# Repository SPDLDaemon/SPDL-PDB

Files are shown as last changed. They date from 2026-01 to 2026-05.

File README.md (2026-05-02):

# Smart Product Design Lab - Power Distribution Board v2.1
## features
* 16 JST XH plugs with 3.3v ground and 5 volts
* 8 molex 254 plugs for servos

## user guide image
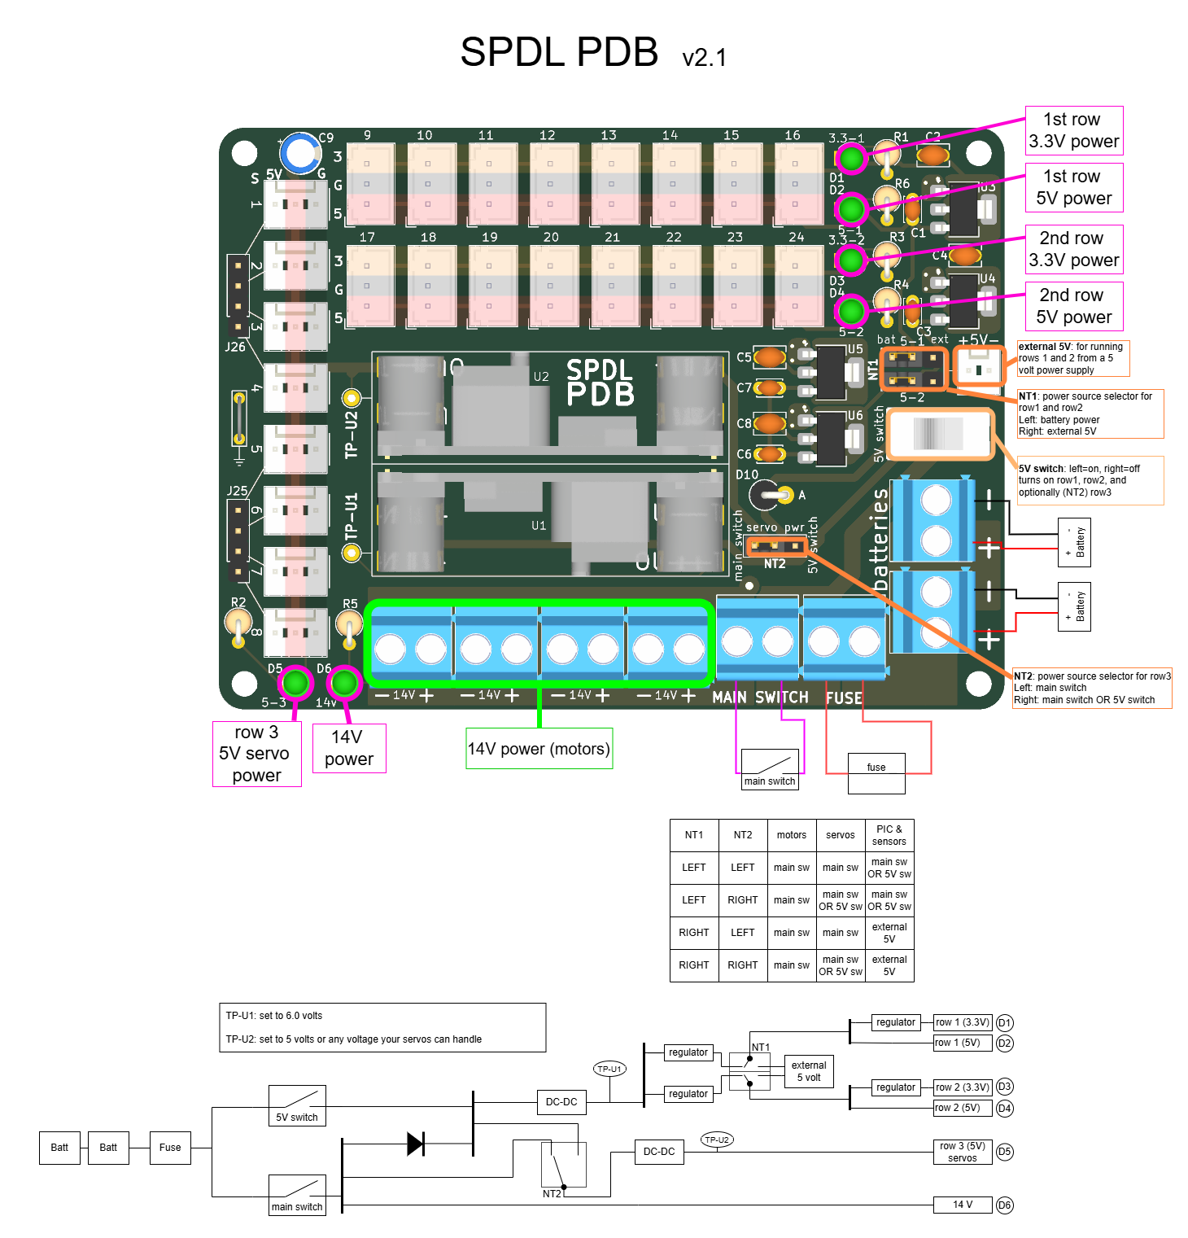
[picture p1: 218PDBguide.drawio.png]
218PDBguide

#### [link to user guide image](/218PDBguide.drawio.png)

### [link to schematic](/schematic.pdf)
#### [link to image of PCB traces](/pcb.pdf)
<!-- ### board explanation video coming soon -->

## assembly
### [assembly instructions](/assembly_instructions.md)

[Interactive BOM](/ibom.html) (download file and open in a browser)

<!-- ### assembly video coming soon -->

## current limits:
* board total: 16 amps (theoretical) ??? amps (tested), limited by the traces and main battery screw terminals
* 5-3: 2 amps (theoretical) ??? amps (tested), limited by the HW-411 buck voltage regulator
* 3.3-1 + 5-1: 1 amp (theoretical) ??? amps (tested), limited by the TLV761 linear voltage regulator
* 3.3-2 + 5-2: 1 amp (theoretical) ??? amps (tested), limited by the TLV761 linear voltage regulator

## images
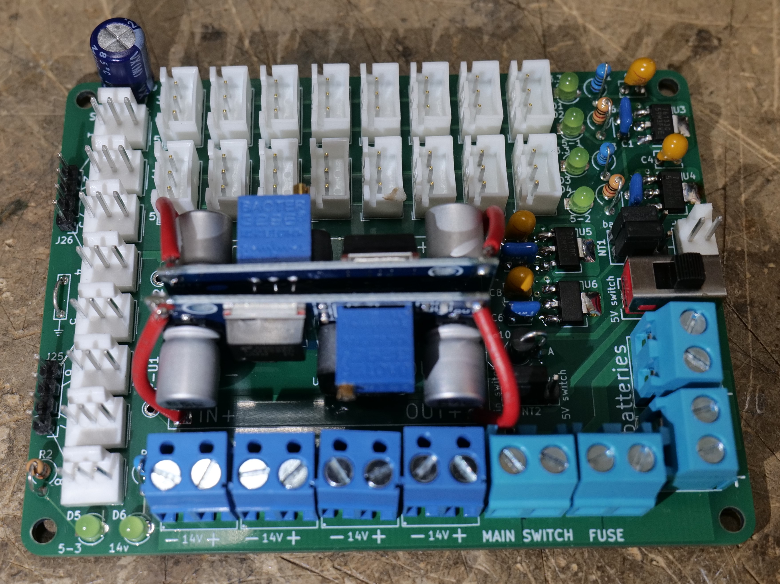
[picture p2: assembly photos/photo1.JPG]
assembled board

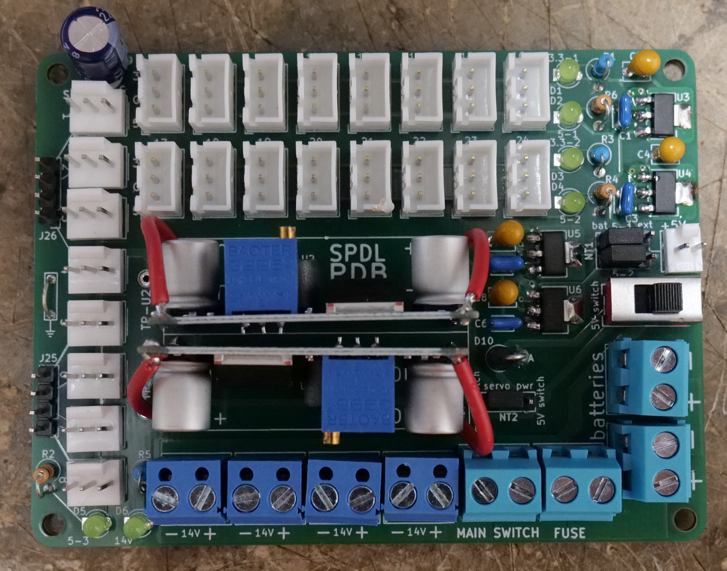
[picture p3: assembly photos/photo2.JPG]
top view


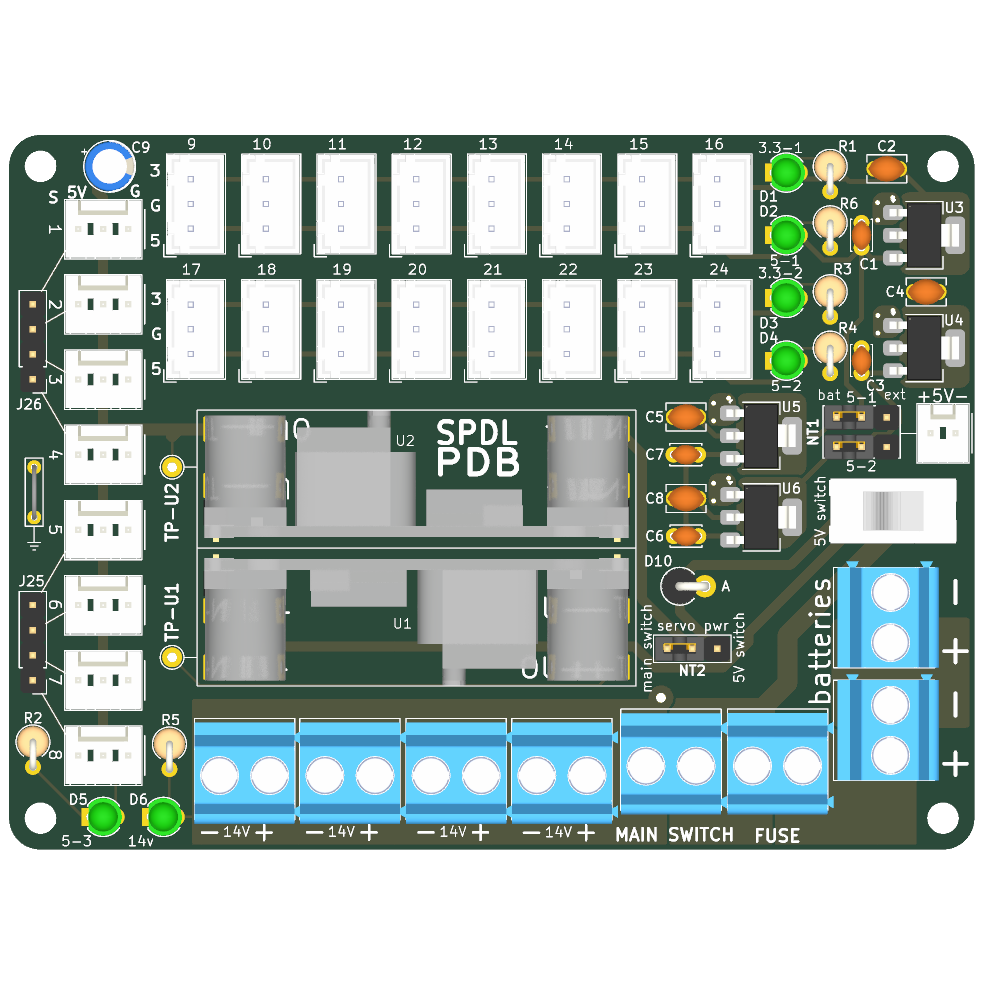
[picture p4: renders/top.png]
render of board

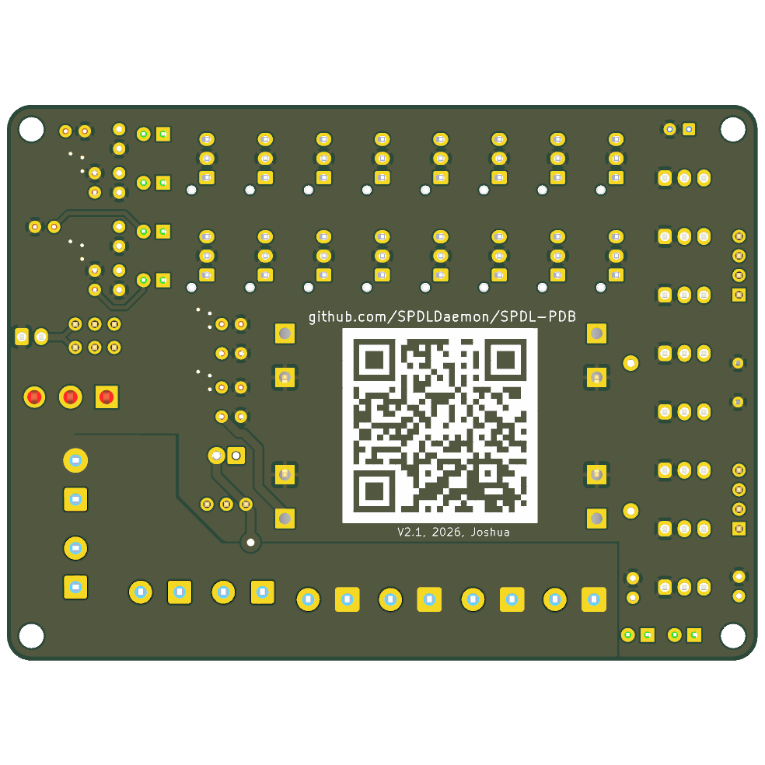
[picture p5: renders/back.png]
render of board back

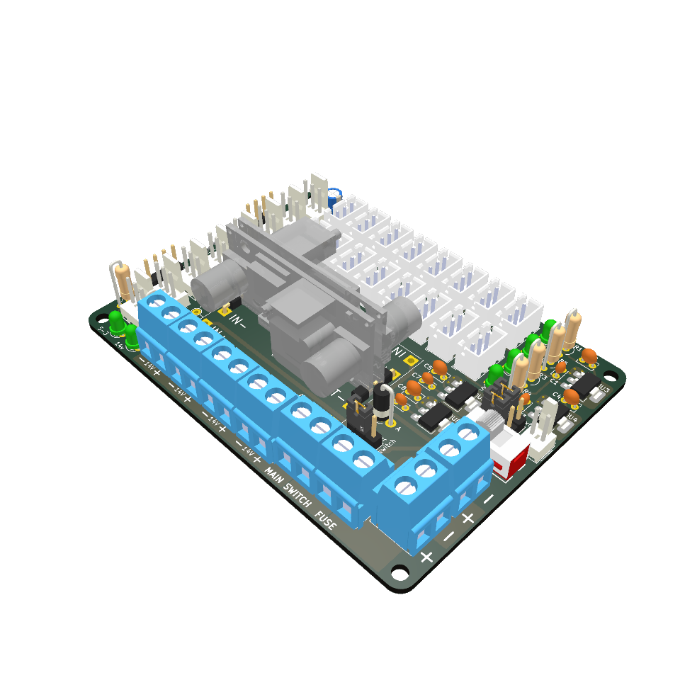
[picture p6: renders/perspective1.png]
render of board perspective1

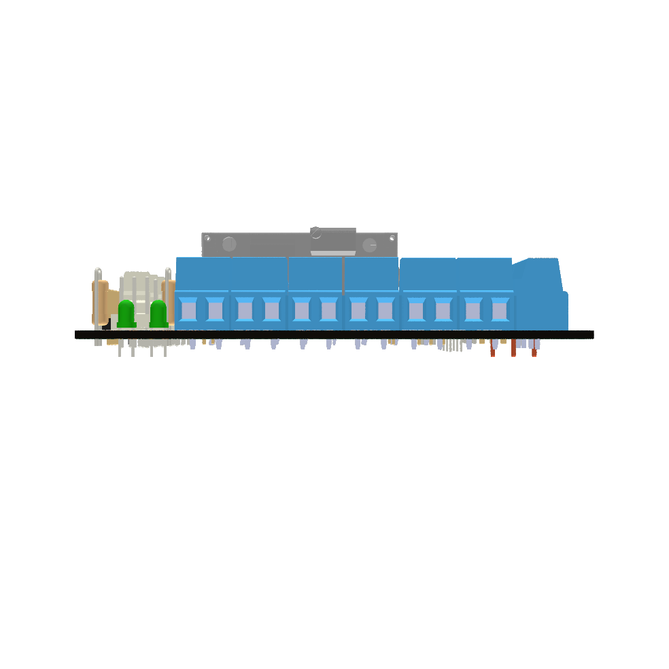
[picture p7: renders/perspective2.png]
render of board perspective2


## KiCAD Symbols
### [simple symbol](https://github.com/SPDLDaemon/SPDL-PDB/blob/main/pdb.kicad_sym)
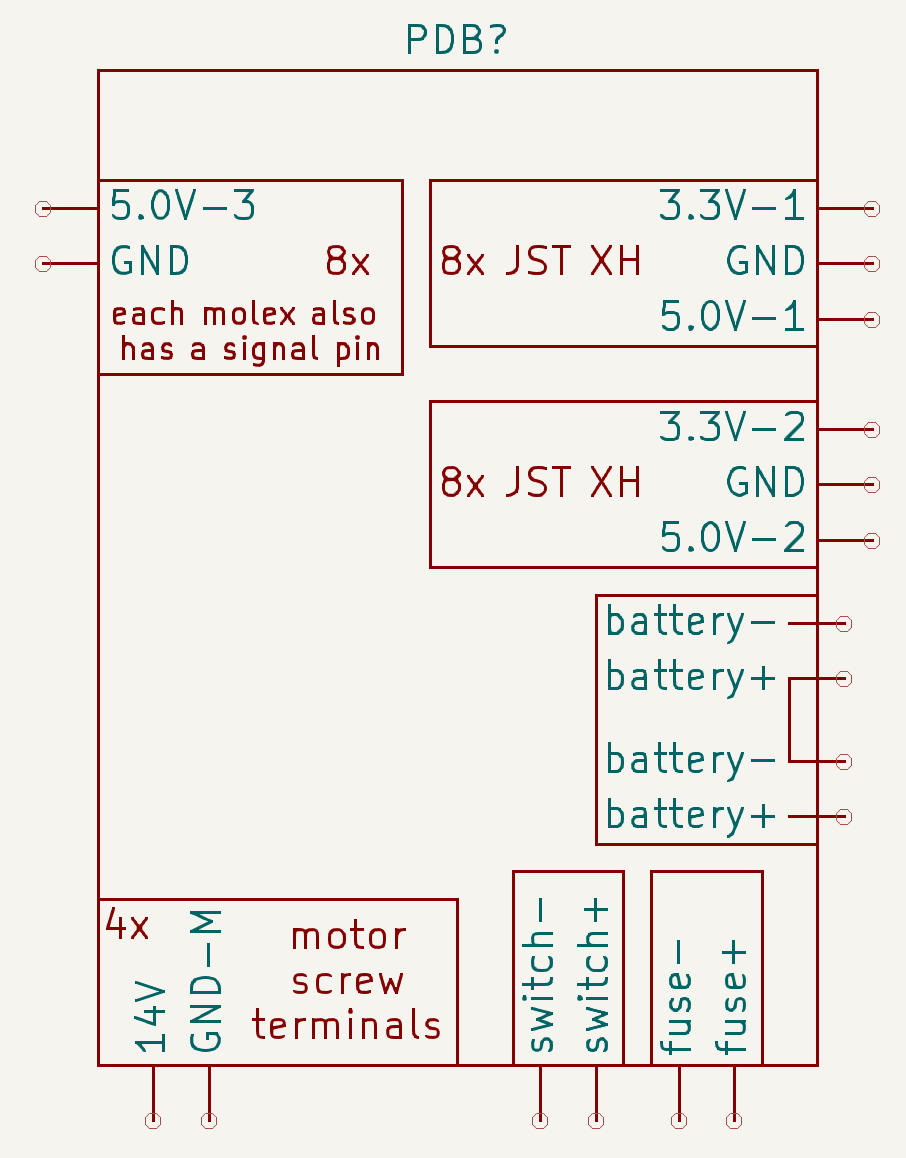
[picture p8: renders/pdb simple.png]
simple

### [detailed symbol](https://github.com/SPDLDaemon/SPDL-PDB/blob/main/pdb-detailed.kicad_sym)
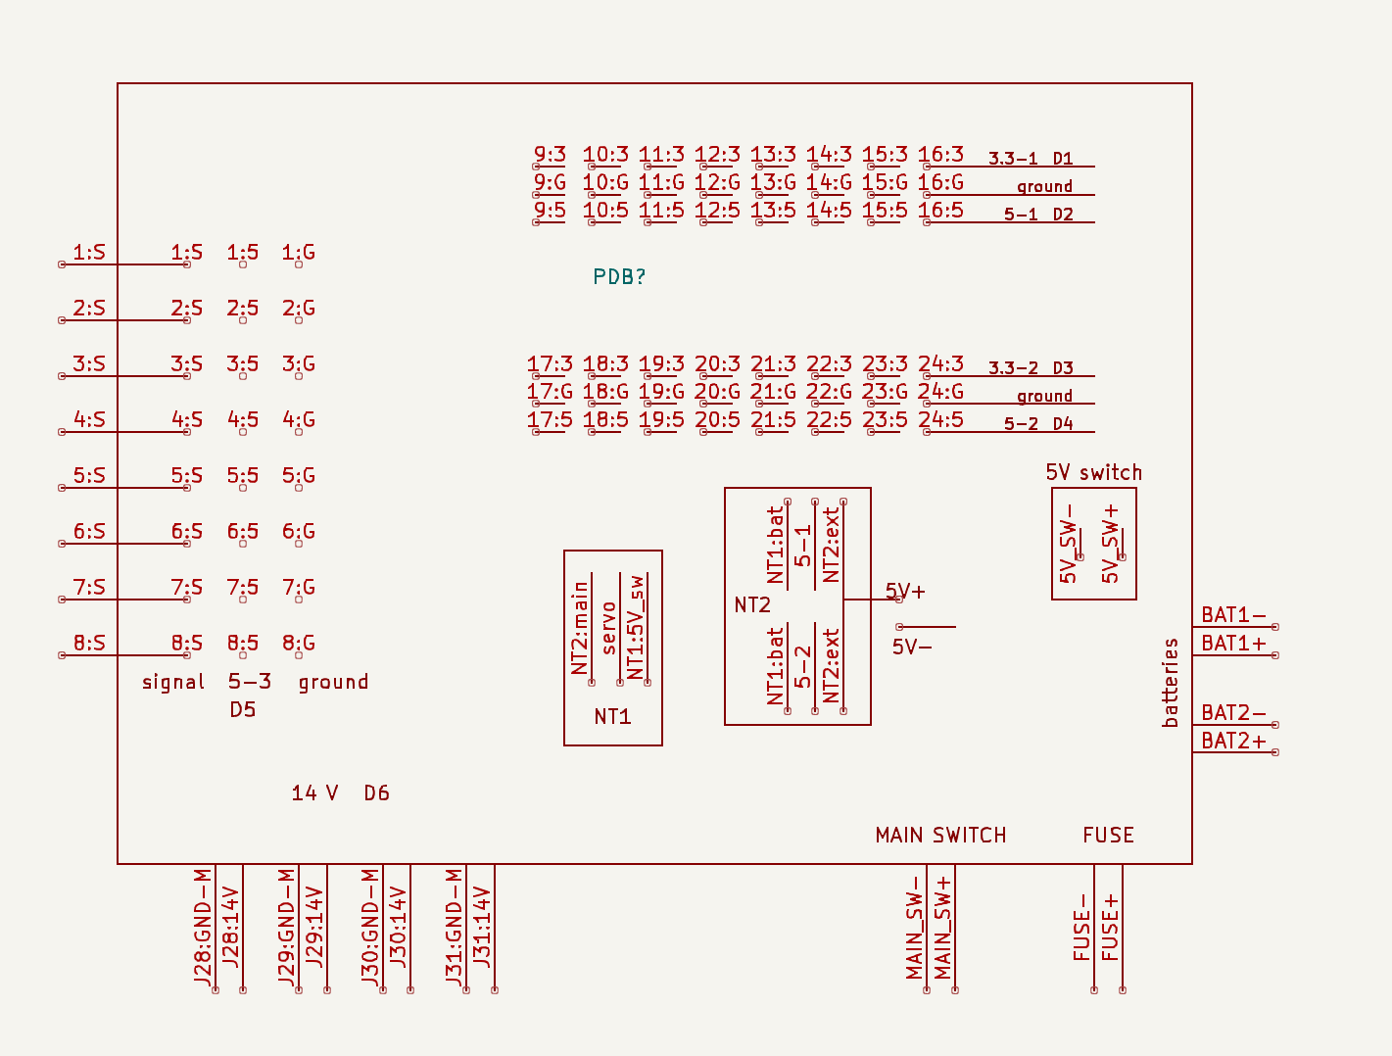
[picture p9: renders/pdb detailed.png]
detailed


## buying PCBs and components 
1x set of components from [bill of materials](/BOM.csv)

2x tamiya connectors for batteries (with wires)

1x main power switch (for example 141-RCA1913F1ABLKBLKWHT3-ND)

1x fuse holder (with wires) and fuse

1x PCB from ([gerber files](/gerbers.zip))

JST XH socket housings (16) 455-2219-ND

JST XH socket crimps (48) 455-1135-1000-ND

4 inches of 18 AWG wire

small flathead screwdriver

JST XH crimper

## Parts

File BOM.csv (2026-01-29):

Reference | Value | Footprint | Part_Number | QUANTITY
C1,C3,C6,C7 | 0.1 uF | Capacitor_THT:C_Disc_D3.0mm_W2.0mm_P2.50mm | 0.1 uF ceramic capacitor | 4
C2,C4,C5,C8 | 10 uF | Capacitor_THT:C_Disc_D3.8mm_W2.6mm_P2.50mm | 10uF tantalum (polarized) capacitor | 4
C9 | 220 uF | Capacitor_THT:CP_Radial_D5.0mm_P2.50mm | 220uf electrolytic | 1
D1-D6 | LED | 218-pdb:LED_D3.0mm | 3 mm diameter LED | 6
D10 | diode, >=2 Amp | Diode_THT:D_DO-15_P2.54mm_Vertical_AnodeUp | >=2 Amp diode, e.g. Diotec 1N5060 | 1
FID1-FID4 | 90 degree header pin | 218-pdb:PinHeader_1x01_P2.54mm_H | 90 degree header pin | 4
FID5,FID6,FID10 | jumper | 218-pdb:jumper | pin jumper 0.1" pitch Sullins QPC02SXGN-RC | 3
Fuse1 | fuse | 218-pdb:CUI_TB007-508-02BE | screw terminal, 5.08" pitch, TB007-508-02BE | 1
J1-J16 | Conn_01x03 | 218-pdb:JST_XH_B3B-XH-AM_1x03_P2.50mm_Vertical | 3 pin JST XH | 16
J17-J24 | Conn_01x03 | 218-pdb:Molex_KK-254_AE-6410-03A_1x03_P2.54mm_Vertical | 3 pin KK254 molex 0022232031 | 8
J25,J26 | Conn_01x04_Pin | Connector_PinHeader_2.54mm:PinHeader_1x04_P2.54mm_Vertical | 4 header pins 0.1" pitch | 2
J27 | external 5V | 218-pdb:Molex_KK-254_AE-6410-02A_1x02_P2.54mm_Vertical | 2 pin KK 254 molex 0022232021 | 1
J28-J31 | 14v | 218-pdb:CUI_TB007-508-02BE | screw terminal, 5.08" pitch, TB007-508-02BE | 4
J32,J33 | battery | 218-pdb:CUI_TB007-508-02BE | screw terminal, 5.08" pitch, TB007-508-02BE | 2
main1 | MainSW | 218-pdb:CUI_TB007-508-02BE | screw terminal, 5.08" pitch, TB007-508-02BE | 1
NT1 | SW_Slide_DPDT | 218-pdb:PinHeader_2x03_P2.54mm_Vertical | 2x3 header pins | 1
NT2 | ~ | 218-pdb:PinHeader_1x03_P2.54mm_Vertical | 3 header pins 0.1" pitch | 1
R1,R3 | 680 | Resistor_THT:R_Axial_DIN0309_L9.0mm_D3.2mm_P2.54mm_Vertical | spdl | 2
R2,R4,R6 | 1k | Resistor_THT:R_Axial_DIN0309_L9.0mm_D3.2mm_P2.54mm_Vertical | spdl | 3
R5 | 3.3k | Resistor_THT:R_Axial_DIN0309_L9.0mm_D3.2mm_P2.54mm_Vertical | spdl | 1
SW1 | 5V switch | 218-pdb:1101A4CQEA | 1101A4CQEA | 1
TP1 | ground | TestPoint:TestPoint_Bridge_Pitch5.08mm_Drill0.7mm | piece of wire | 1
U1,U2 | DC-DC buck | 218-pdb:HW-411 | HW-411 lm2596 buck converter module | 2
U3,U4 | TLV76133DCY | Package_TO_SOT_SMD:SOT-223-3_TabPin2 | TLV76133DCY | 2
U5,U6 | TLV76150DCY | Package_TO_SOT_SMD:SOT-223-3_TabPin2 | TLV76150DCY | 2

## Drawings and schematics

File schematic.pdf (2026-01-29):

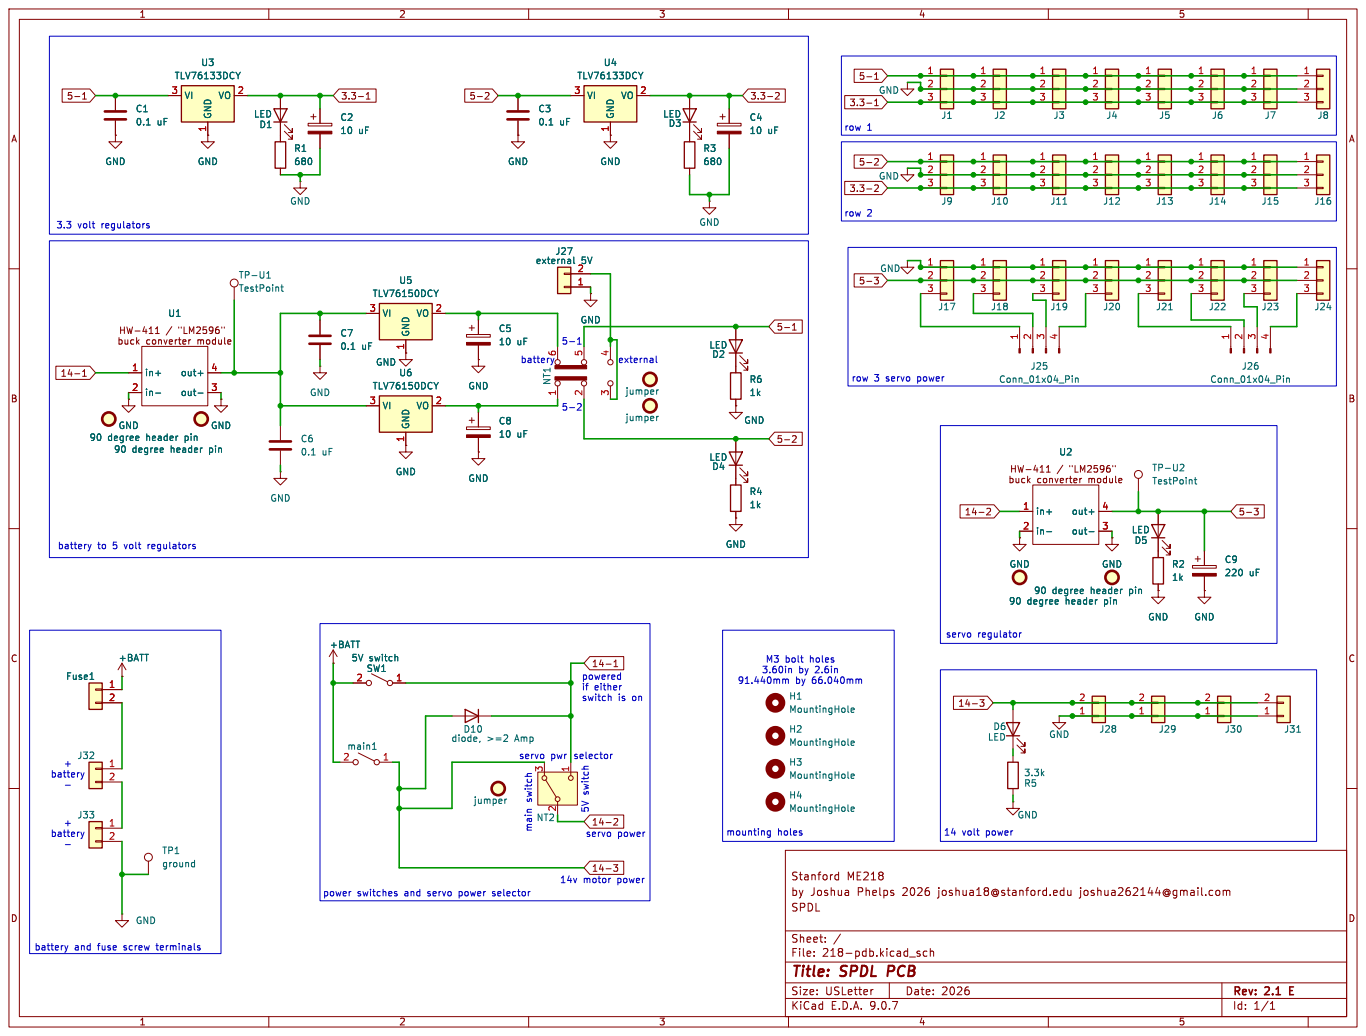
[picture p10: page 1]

J26 Conn_01x04_Pin C6
row 3 servo power power switches and servo power selector
10 uF GND

90 degree header pin GND

battery to 5 volt regulators

powered
if either switch is on

File: 218-pdb.kicad_sch Sheet: / SPDL

battery and fuse screw terminals

Id: 1/1 Title: SPDL PCB

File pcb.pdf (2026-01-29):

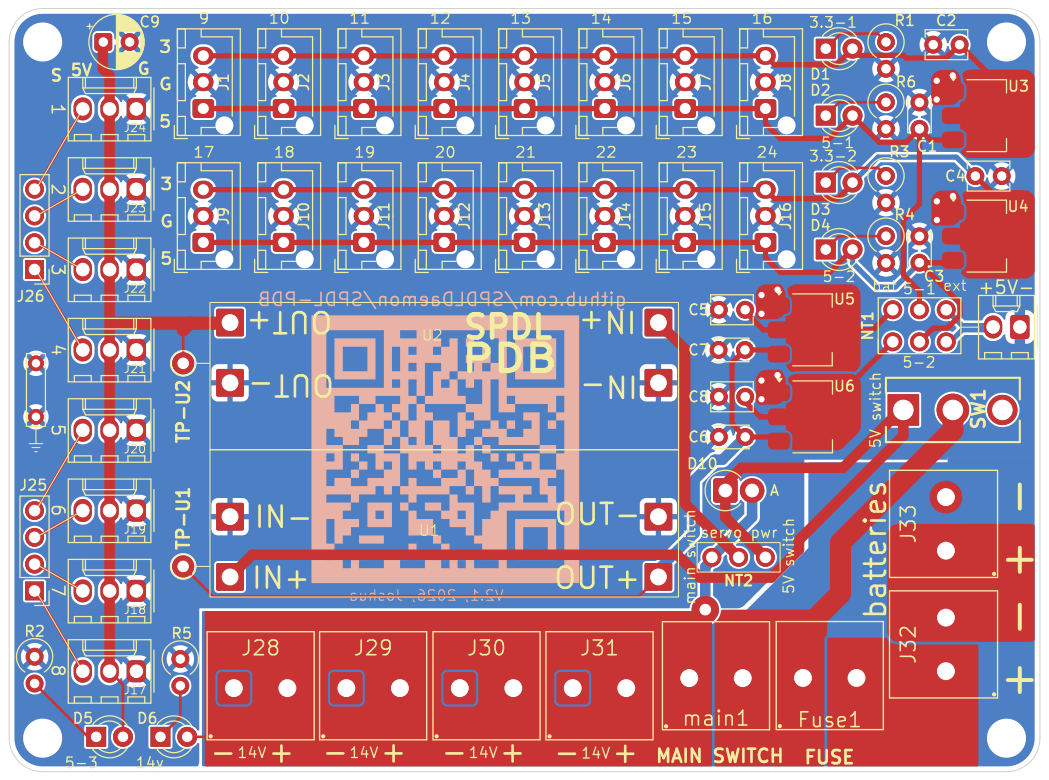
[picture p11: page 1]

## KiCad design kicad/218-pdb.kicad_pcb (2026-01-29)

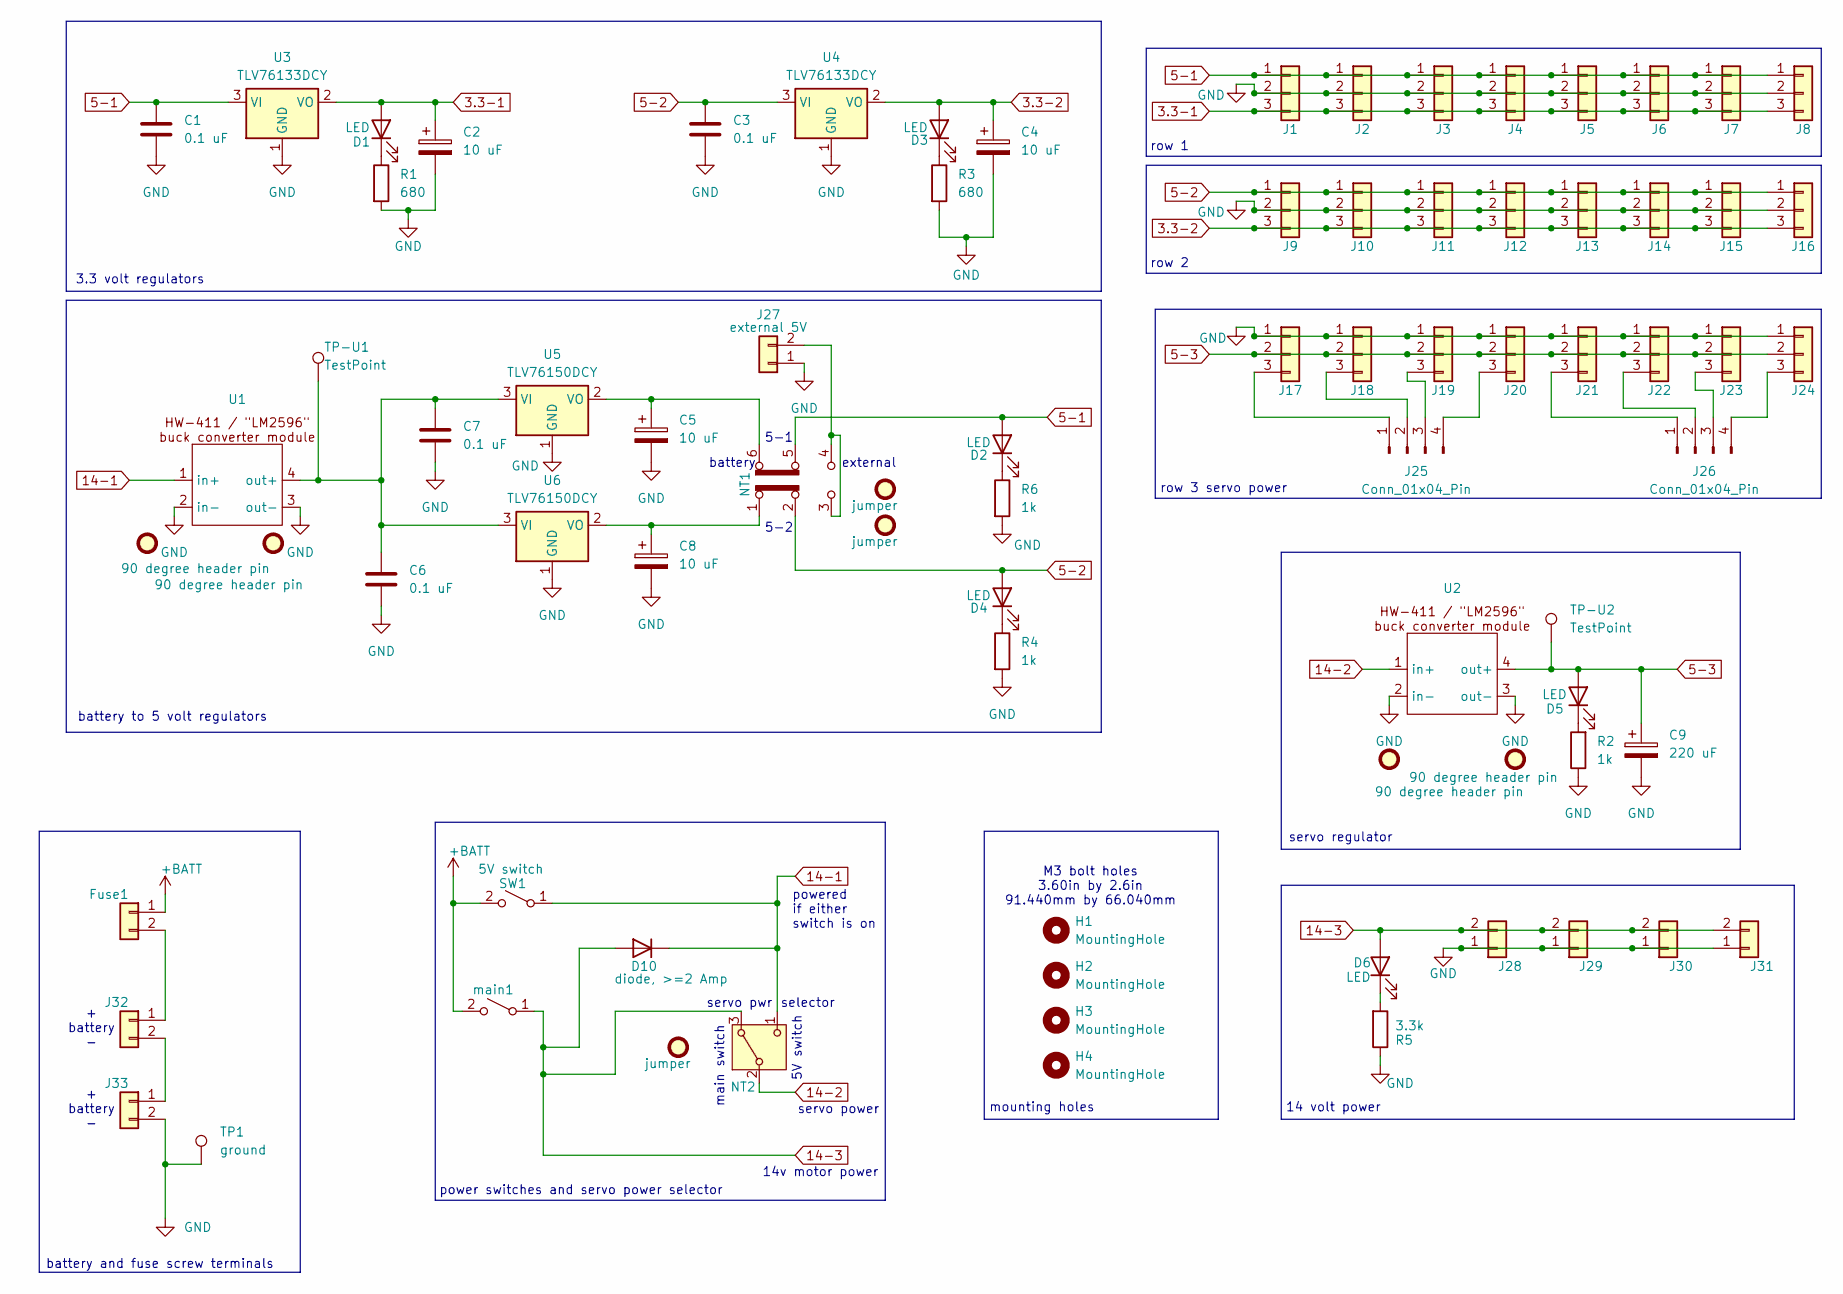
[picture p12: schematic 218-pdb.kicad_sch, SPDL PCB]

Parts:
C1, C3, C6, C7: 0.1 uF; C_Disc_D3.0mm_W2.0mm_P2.50mm; Part_Number 0.1 uF ceramic capacitor
C2, C4, C5, C8: 10 uF; C_Disc_D3.8mm_W2.6mm_P2.50mm; Part_Number 10uF tantalum (polarized) capacitor
C9: 220 uF; CP_Radial_D5.0mm_P2.50mm; Part_Number 220uf electrolytic
D1, D2, D3, D4, D5, D6: LED; LED_D3.0mm; Part_Number 3 mm diameter LED
D10: diode, >=2 Amp; D_DO-15_P2.54mm_Vertical_AnodeUp; Part_Number >=2 Amp diode, e.g. Diotec 1N5060
FID1, FID2, FID3, FID4: 90 degree header pin; PinHeader_1x01_P2.54mm_H; Part_Number 90 degree header pin
FID5, FID6, FID10: jumper; Part_Number pin jumper 0.1" pitch Sullins QPC02SXGN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
Fuse1: fuse; CUI_TB007-508-02BE; Part_Number screw terminal, 5.08" pitch, TB007-508-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
H1, H2, H3, H4: MountingHole; MountingHole_3.2mm_M3_ISO7380
J1, J2, J3, J4, J5, J6, J7, J8, J9, J10, J11, J12, J13, J14, J15, J16: Conn_01x03; JST_XH_B3B-XH-AM_1x03_P2.50mm_Vertical; Part_Number 3 pin JST XH
J17, J18, J19, J20, J21, J22, J23, J24: Conn_01x03; Molex_KK-254_AE-6410-03A_1x03_P2.54mm_Vertical; Part_Number 3 pin KK254 molex 0022232031
J25, J26: Conn_01x04_Pin; PinHeader_1x04_P2.54mm_Vertical; Part_Number 4 header pins 0.1" pitch
J27: external 5V; Molex_KK-254_AE-6410-02A_1x02_P2.54mm_Vertical; Part_Number 2 pin KK 254 molex 0022232021
J28, J29, J30, J31: 14v; CUI_TB007-508-02BE; Part_Number screw terminal, 5.08" pitch, TB007-508-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
J32, J33: battery; CUI_TB007-508-02BE; Part_Number screw terminal, 5.08" pitch, TB007-508-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
NT1: SW_Slide_DPDT; PinHeader_2x03_P2.54mm_Vertical; Part_Number 2x3 header pins
NT2: PinHeader_1x03_P2.54mm_Vertical; Part_Number 3 header pins 0.1" pitch
R1, R3: 680; R_Axial_DIN0309_L9.0mm_D3.2mm_P2.54mm_Vertical; Part_Number spdl; digikey_part_number n/a
R2, R4, R6: 1k; R_Axial_DIN0309_L9.0mm_D3.2mm_P2.54mm_Vertical; Part_Number spdl; digikey_part_number n/a
R5: 3.3k; R_Axial_DIN0309_L9.0mm_D3.2mm_P2.54mm_Vertical; Part_Number spdl; digikey_part_number n/a
SW1: 5V switch; 1101A4CQEA; Part_Number 1101A4CQEA; digikey_part_number 2449-1101A4CQEA-ND
TP1: ground; TestPoint_Bridge_Pitch5.08mm_Drill0.7mm; Part_Number piece of wire
TP-U1, TP-U2: TestPoint; TestPoint_THTPad_D2.0mm_Drill1.0mm
U1, U2: DC-DC buck; HW-411; Part_Number HW-411 lm2596 buck converter module; digikey_part_number n/a
U3, U4: TLV76133DCY; SOT-223-3_TabPin2; Part_Number TLV76133DCY
U5, U6: TLV76150DCY; SOT-223-3_TabPin2; Part_Number TLV76150DCY
main1: MainSW; CUI_TB007-508-02BE; Part_Number screw terminal, 5.08" pitch, TB007-508-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

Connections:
3.3-1: C2.1, D1.2 (A), J1.3, J2.3, J3.3, J4.3, J5.3, J6.3, J7.3, J8.3, U3.2 (VO)
3.3-2: C4.1, D3.2 (A), J9.3, J10.3, J11.3, J12.3, J13.3, J14.3, J15.3, J16.3, U4.2 (VO)
5-1: C1.1, D2.2 (A), J1.1, J2.1, J3.1, J4.1, J5.1, J6.1, J7.1, J8.1, NT1.5 (B), U3.3 (VI)
5-2: C3.1, D4.2 (A), J9.1, J10.1, J11.1, J12.1, J13.1, J14.1, J15.1, J16.1, NT1.2 (B), U4.3 (VI)
5-3: C9.1, D5.2 (A), J17.2, J18.2, J19.2, J20.2, J21.2, J22.2, J23.2, J24.2, TP-U2.1, U2.4 (out+)
14-1: D10.1 (K), NT2.1 (C), SW1.1 (A), U1.1 (in+)
14-2: NT2.2 (B), U2.1 (in+)
14-3: D6.2 (A), D10.2 (A), J28.2, J29.2, J30.2, J31.2, NT2.3 (A), main1.1 (A)
+BATT: Fuse1.1, SW1.2 (B), main1.2 (B)
GND: C1.2, C2.2, C3.2, C4.2, C5.2, C6.2, C7.2, C8.2, C9.2, J1.2, J2.2, J3.2, J4.2, J5.2, J6.2, J7.2, J8.2, J9.2, J10.2, J11.2, J12.2, J13.2, J14.2, J15.2, J16.2, J17.1, J18.1, J19.1, J20.1, J21.1, J22.1, J23.1, J24.1, J27.1, J28.1, J29.1, J30.1, J31.1, J33.2, R1.2, R2.1, R3.2, R4.2, R5.1, R6.2, TP1.1, U1.2 (in-), U1.3 (out-), U2.2 (in-), U2.3 (out-), U3.1 (GND), U4.1 (GND), U5.1 (GND), U6.1 (GND)
unnamed: D1.1 (K), R1.1
unnamed: D2.1 (K), R6.1
unnamed: D3.1 (K), R3.1
unnamed: D4.1 (K), R4.1
unnamed: D5.1 (K), R2.2
unnamed: D6.1 (K), R5.2
unnamed: Fuse1.2, J32.1
unnamed: J17.3, J25.1
unnamed: J18.3, J25.2
unnamed: J19.3, J25.3
unnamed: J20.3, J25.4
unnamed: J21.3, J26.1
unnamed: J22.3, J26.2
unnamed: J23.3, J26.3
unnamed: J24.3, J26.4
unnamed: J27.2, NT1.3 (C), NT1.4 (A)
unnamed: J32.2, J33.1
unnamed: C6.1, C7.1, TP-U1.1, U1.4 (out+), U5.3 (VI), U6.3 (VI)
unnamed: C5.1, NT1.6 (C), U5.2 (VO)
unnamed: C8.1, NT1.1 (A), U6.2 (VO)

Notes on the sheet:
battery to 5 volt regulators
mounting holes
battery
battery and fuse screw terminals
selector
external
+ battery -
row 1
M3 bolt holes 3.60in by 2.6in 91.440mm by 66.040mm
servo regulator
row 2
3.3 volt regulators
power switches and servo power selector
5-1
servo pwr
5-2
row 3 servo power
5V switch
powered if either switch is on
main switch
14 volt power
14v motor power
servo power

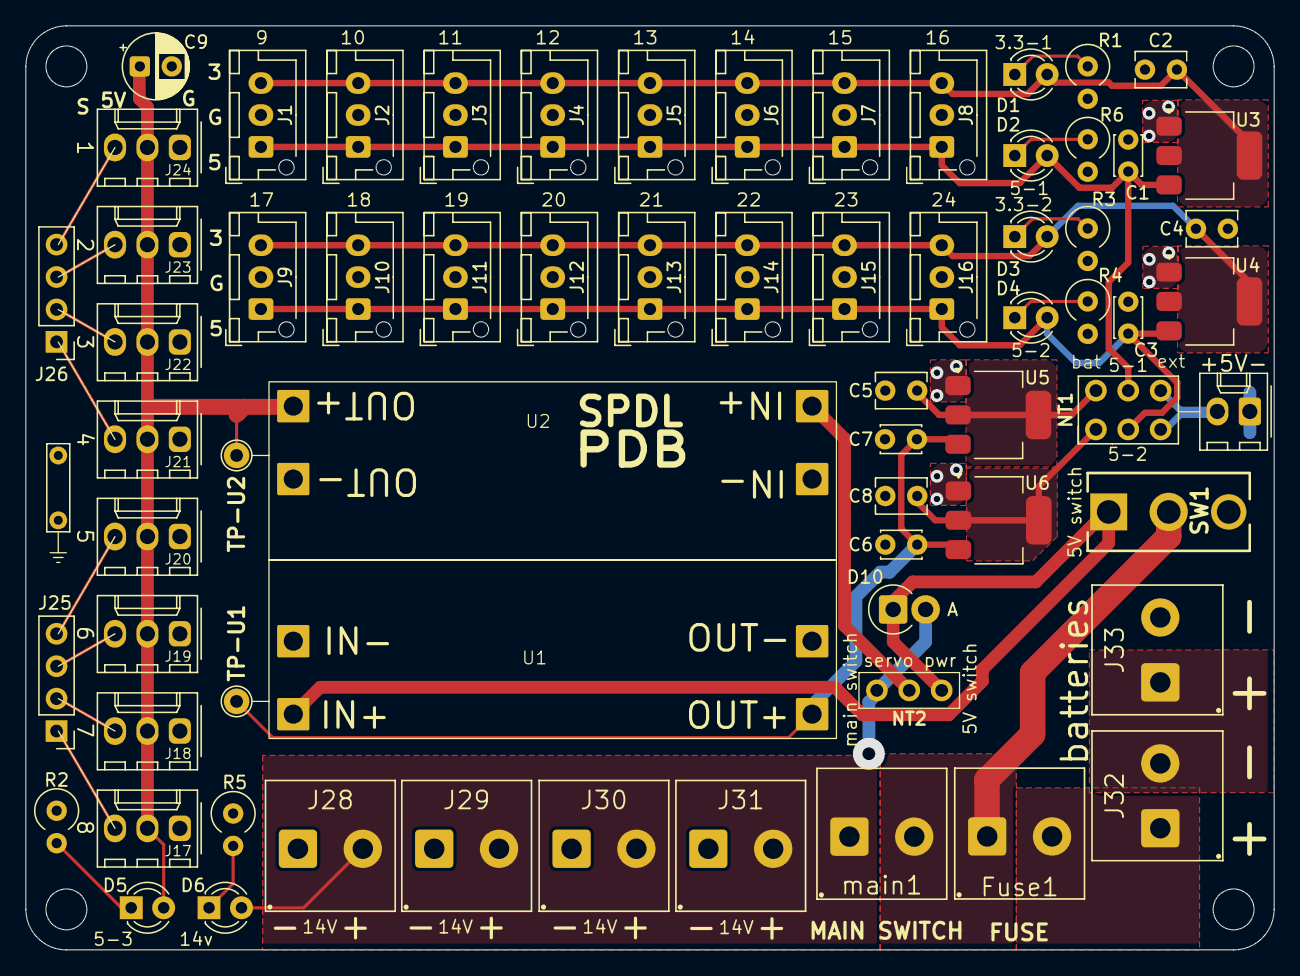
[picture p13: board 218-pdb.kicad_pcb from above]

Board: 2 copper layers, 97.8 x 72.4 mm, 80 parts (0 on the bottom side), 30 nets.

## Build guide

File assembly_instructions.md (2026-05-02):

# SPDL PDB Assembly Instructions

## tools needed
* soldering iron
* solder
* wire cutters
* wire strippers
* needle nose pliers
* multimeter
* small flathead screwdriver

## parts needed

* 1x PCB

* 1x set of components from [bill of materials](/BOM.csv)

* 2x tamiya connectors for batteries (with wires)

* 1x main power switch

* 1x fuse holder (with wires) and fuse

* 4 1-inch pieces of 18 AWG wire

* 2 batteries

[Interactive BOM](/ibom.html) (download file and open in a browser)

## Time to Solder!

### TLV76150DCY: U5, U6
There are two types of voltage regulators that look very similar.

Make sure you see "150" in the code on the top of the chips.

### TLV76133DCY: U3, U4
Make sure you see "133" in the code on the top of the chips.

### leds: D1-D6, the long lead is the positive lead and goes in the round hole to the right for each led.

### 0.1uF (104) capacitors: C1, C3, C6, C7

### 10uf capacitors:

C2: positive lead is on the right near the mounting hole

C4: positive lead is on the left farther from the edge of the board

C5, C8: positive leads are on the right closer to U5 and U6

### 680 ohm resistors: R1, R3

### 1k ohm resistors: R2, R4, R6

### 3.3k ohm resistor: R5

### Diode: D10, the banded end is the negative end and goes in the square hole on the left while the positive end goes in the round hole labeled A

### 3 header pins: 2 sets of 3 for NT1 and 1 set of 3 for NT2

### 4 header pins: J25, J26

### Molex 254 2 pin connector: 5V

### small switch: SW1

### buck converters: U1, U2
use 90 degree header pins FID1-FID4, trim the pins so that they don't touch each other

also use 4 wires to connect the IN+ and OUT+ wires

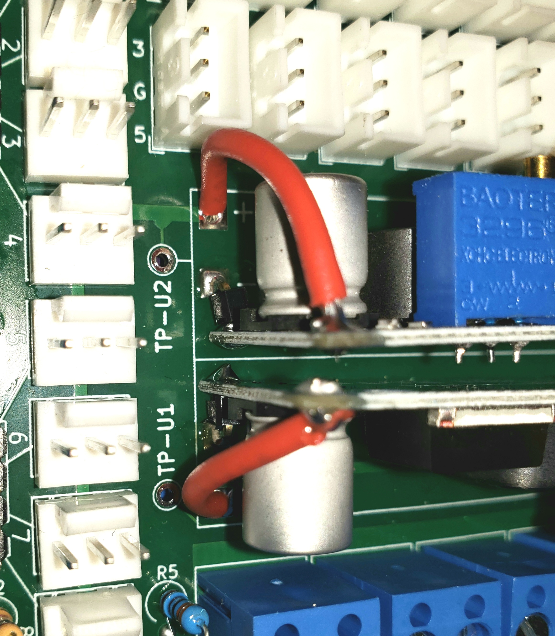
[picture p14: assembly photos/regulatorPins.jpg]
buck converter wiring


### JST XH 3 pin connectors: J1-J16

### Molex 254 3 pin connectors: J17-J24

### Screw terminal blocks: J28-J31 for 14v, J32-J33 for battery, main1 for main switch

### 220uF capacitor: C9, the gray negative terminal stripe goes to the right.

### piece of wire (use a resistor lead you trimmed): TP1, connect the two pads together to make a loop where you can clip an oscilloscope ground.

assembled board

## Turning on the PDB for the first time

#### Screw terminals are in the closed position when you first get them. Turn the screws counterclockwise as far as you can to open the terminals before connecting wires. Turn the screws clockwise to tighten the terminals on the wires.

Connect the wires of the tamiya plugs to the battery screw terminals, making sure to connect the positive wire to the positive terminal and the negative wire to the negative terminal.

Solder wires to the main power switch

Connect the main power switch to the MAIN SWITCH screw terminal. Polarity doesn't matter for the switch.

Connect the fuse holder to the FUSE screw terminal. Polarity doesn't matter for the fuse. If the ends of the wires are covered in solder, cut the solder off and strip the ends of the wires.

Make sure that the two jumpers for NT1 are not installed.

Plug 1 shunt jumper into NT2, with the jumper on the left side of the board.

Make sure that the main power switch is off.

Make sure that the 5V switch is off (towards the edge of the board).

Plug charged batteries into the tamiya connectors.

Turn on the main power switch. If there is smoke turn the switch back off.

Use a multimeter to measure the voltage between TP-U1 and the ground wire on the left of the board. 

Adjust the screw on the U1 voltage regulator until TP-U1 is at 6.0 volts. Counterclockwise will decrease the voltage and clockwise will increase the voltage.

Use a multimeter to measure the voltage between TP-U2 and the ground wire on the left of the board.

Adjust the screw on the U2 voltage regulator until TP-U2 is at 5.0 volts (or whatever voltage you want to supply to your servos and any other components you connect to the molex connectors).

Turn the main power switch back off.

Plug 2 shunt jumpers into NT1, both on the left side.

Turn the main power switch back on. If there is smoke turn the switch back off.

All 6 lights should be on at similar brightness. You can use a multimeter to check that all the pins are supplying the correct voltages.

Turn the main power switch back off.

Turn the 5V switch on and check that D1,D2,D3,D4 are on and that D6 is off.

Turn the PDB back off (and remember to turn it off whenever you are working on your circuit).

### Congrats, your PDB is ready to use!

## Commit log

2026-01-01 edit silkscreen
    [218-pdb.kicad_pcb]
2026-01-01 align silkscreen
    [218-pdb.kicad_pcb]
2026-01-02 update BOM, silkscreen
    [218-pdb.kicad_pcb, 218-pdb.kicad_sch]
2026-01-02 BOT process kicad
    [BOM.csv]
2026-01-03 update bom
2026-01-03 change diode
    [218-pdb.kicad_pcb, 218-pdb.kicad_sch]
2026-01-04 start diagram
    [218-pdb.kicad_pcb, 218-pdb.kicad_sch]
2026-01-07 update silkscreen
    [218-pdb.kicad_pcb]
2026-01-17 start design E
    [218-pdb.kicad_pcb, 218-pdb.kicad_sch]
2026-01-19 change schematic and start layout
    [218-pdb.kicad_pcb, 218-pdb.kicad_sch]
2026-01-19 edit switch
    [218-pdb.kicad_pcb]
2026-01-19 add traces
    [218-pdb.kicad_pcb, 218-pdb.kicad_sch]
2026-01-22 adjust layout
    [218-pdb.kicad_pcb]
2026-01-22 work on diagram and silkscreen
    [218-pdb.kicad_pcb]
2026-01-26 align silkscreen and edit diagram
    [218-pdb.kicad_pcb]
2026-01-29 add fuse terminal
    [218-pdb.kicad_pcb, 218-pdb.kicad_sch]
2026-01-29 align silkscreen and comment schematic
    [218-pdb.kicad_pcb, 218-pdb.kicad_sch]
2026-01-29 change jst xh model
    [218-pdb.kicad_pcb, 218-pdb.kicad_sch]
2026-01-29 advice from Karl
    [218-pdb.kicad_pcb, 218-pdb.kicad_sch]
2026-02-07 assembly instructions in progress
2026-02-12 Update README with KiCAD symbols section
    Added KiCAD symbols section with links to simple and detailed symbols.
2026-02-12 add 5v switch to symbol
2026-02-14 add assembly picture
2026-02-14 add testing to assembly instructions
2026-02-15 correct errors in assembly instructions, thanks Gus!
2026-02-17 add note about screw terminals
2026-02-17 add note about tinned fuse holder ends
2026-02-19 add note about regulators looking similar
2026-02-19 label external 5v plug
